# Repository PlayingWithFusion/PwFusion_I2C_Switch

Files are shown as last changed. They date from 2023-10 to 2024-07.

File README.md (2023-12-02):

# PwFusion_I2C_Switch

Are you looking for a way to take your project to the next level? Playing with Fusion's I2C Switch board is the way to go! This device greatly simplifies connectivity to a microcontroller through the QWIIC system. The typical 2 wires required to a toggle switch with a microcontroller can be reduced to one QWIIC cable. You can even chain multiple QWIIC devices together for maximum wiring efficiency! If that isn't enough, Playing with Fusion provides Arduino libraries to make writing code for these boards as easy as possible! Weather you are a beginner looking for a simple introduction to the world of hobbyist electronics or an advanced user looking for a rapid prototyping tool, Playing with Fusion's I2C Switch is right for you!

## I2C Addresses

| ADR | Address |
| --- | --- |
| uncut | 0x13  |
| cut | 0x14  |

Each Playing with Fusion I2C switch board comes with 2 available I2C addresses, which can be easily selected by disconnecting a jumper on the printed circuit board. This allows for 2 toggle switch boards to be used on the same QWIIC chain. If you would like more than 2, see docs/Programming Instructions and flash a modified firmware with additional I2C address options.

## Example Projects
RC Transmitter: https://github.com/PlayingWithFusion/RC_Transmitter

## Related
| Page | Link |
| --- | --- |
| PwFusion_I2C_Toggle_Arduino_Library: | https://github.com/PlayingWithFusion/PwFusion_I2C_Toggle_Arduino_Library |
| PwFusion_Data_Transfer: | https://github.com/PlayingWithFusion/PwFusion_Data_Transfer |
| IFB-40001 PwFusion_I2C_Encoder: | https://github.com/PlayingWithFusion/PwFusion_I2C_Encoder |
| IFB-40002 PwFusion_I2C_Joystick:  |  https://github.com/PlayingWithFusion/PwFusion_I2C_Joystick |
| IFB-40003 PwFusion_I2C_Switch: | https://github.com/PlayingWithFusion/PwFusion_I2C_Switch |
| IFB-40004 PwFusion_I2C_Buttons:  | https://github.com/PlayingWithFusion/PwFusion_I2C_Buttons |

Visit https://www.playingwithfusion.com/ for more information.

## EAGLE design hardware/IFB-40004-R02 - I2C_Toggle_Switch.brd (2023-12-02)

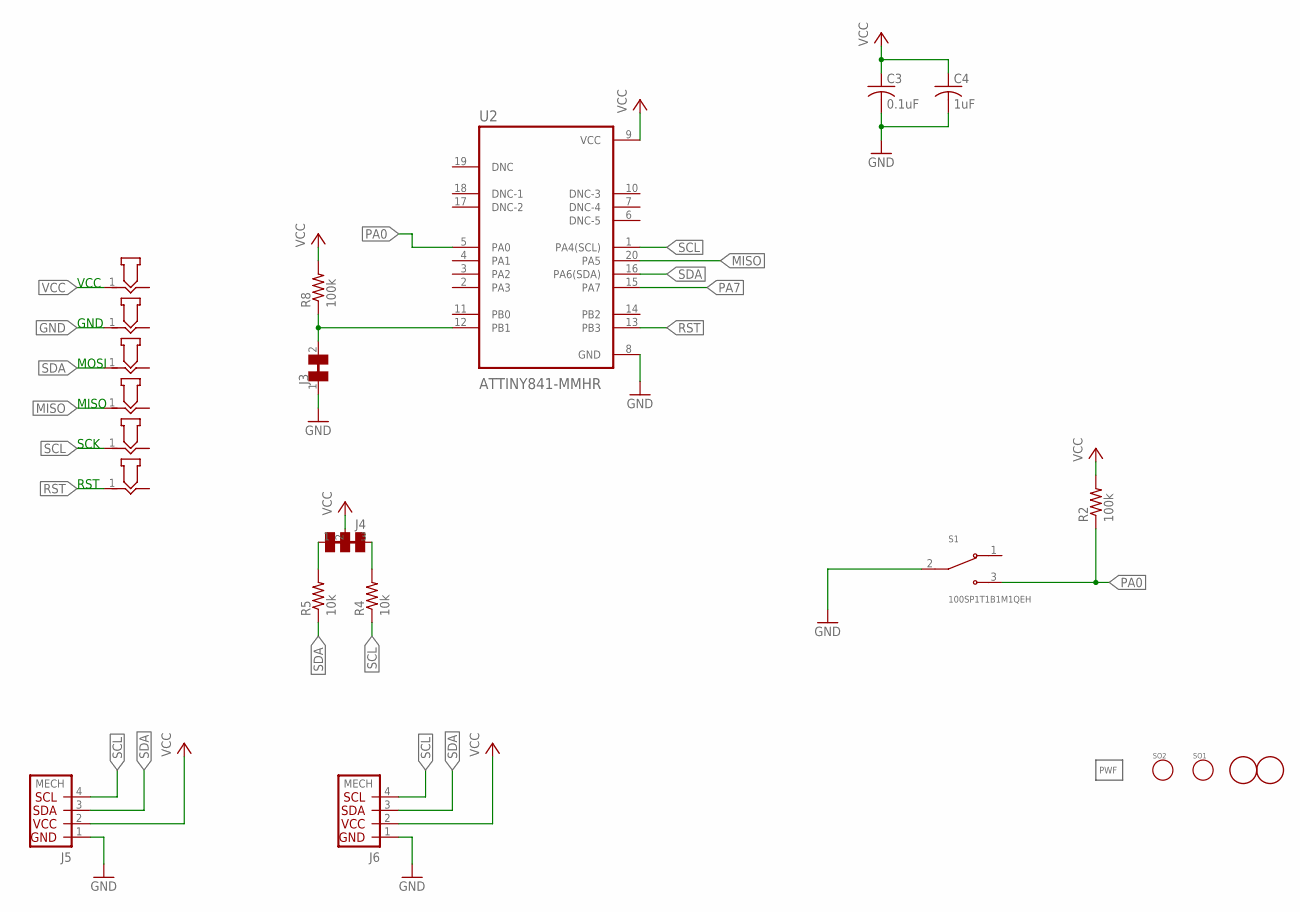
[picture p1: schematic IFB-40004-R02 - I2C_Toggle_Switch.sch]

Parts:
C3: 0.1uF; C0603K
C4: 1uF; C0603K
GND: POGO_PAD; P50_POGO_BOARD_CONTACT_12MIL
J3: CUTTABLE_JUMPER; SMT_CUTTABLE_JUMPER
J4: CUT_JUMPER_2X; SMT_2X_CUTTABLE_JUMPER
J5, J6: QWIICSIDE; SM04B-SRSS-TB
LOGO1: PWF_LOGOPWF-5MM-SS; LOGO_5MM_STEIN
MISO: POGO_PAD; P50_POGO_BOARD_CONTACT_12MIL
MOSI: POGO_PAD; P50_POGO_BOARD_CONTACT_12MIL
R2, R8: 100k; R0603
R4, R5: 10k; R0603
RST: POGO_PAD; P50_POGO_BOARD_CONTACT_12MIL
S1: 100SP1T1B1M1QEH; SW_100SP1T1B1M1QEH
SCK: POGO_PAD; P50_POGO_BOARD_CONTACT_12MIL
SO1, SO2: STAND_OFFNO4_TIGHT; STANDOFF_NO4_TIGHT
U2: ATTINY841-MMHR; QFN45P300X300X85-21N
U$2, U$3: FIDUCIAL; FIDUCIAL_1MM
VCC: POGO_PAD; P50_POGO_BOARD_CONTACT_12MIL

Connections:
GND: C3.2, C4.2, GND.1, J3.1, J5.1, J6.1, S1.2, U2.8 (GND)
MISO: MISO.1, U2.20 (PA5)
unnamed: J3.2, R8.1, U2.12 (PB1)
unnamed: J4.1, R5.2
unnamed: J4.3, R4.2
PA0: R2.1, S1.3, U2.5 (PA0)
PA7: U2.15 (PA7)
RST: RST.1, U2.13 (PB3)
SCL: J5.4, J6.4, R4.1, SCK.1, U2.1 (PA4(SCL))
SDA: J5.3, J6.3, MOSI.1, R5.1, U2.16 (PA6(SDA))
VCC: C3.1, C4.1, J4.2, J5.2, J6.2, R2.2, R8.2, U2.9 (VCC), VCC.1

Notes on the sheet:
VCC
GND
MOSI
MISO
SCK
RST

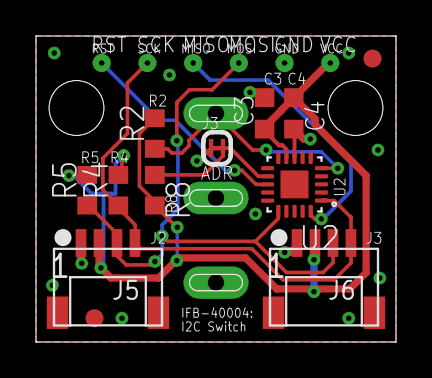
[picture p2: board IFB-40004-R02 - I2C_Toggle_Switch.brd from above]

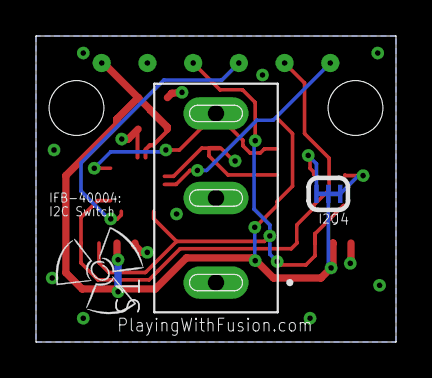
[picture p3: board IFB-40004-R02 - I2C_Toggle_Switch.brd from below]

Board: 2 copper layers, 20.0 x 17.0 mm, 23 parts (3 on the bottom side), 10 nets.

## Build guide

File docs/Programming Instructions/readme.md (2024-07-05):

# Programming Instructions

## Introduction
If you find yourself needing to make changes to the firmware on an interface board, follow these steps to flash your own firmware onto the embedded microcontroller.

All that is required to reporgram a Playing with Fusion I2C board is an AVR programmer. These are available in many forms. This document will cover 2 methods, using a dedicated AVR programmer from Sparkfun and using an Arduino Uno.

## Setup

First, you will need to install the ATtiny Core boards package for the arduino IDE. 

---

**Step 1**

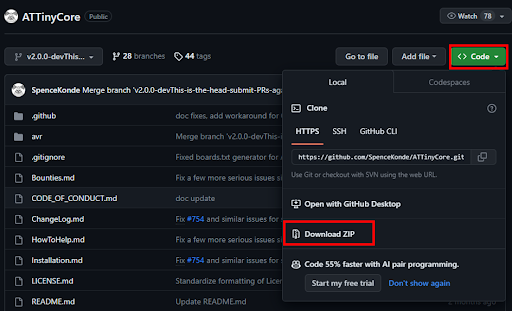
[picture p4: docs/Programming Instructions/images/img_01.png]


Follow the link [here](https://github.com/SpenceKonde/ATTinyCore/tree/v2.0.0-devThis-is-the-head-submit-PRs-against-this) and download the zip file.

---

**Step 2**



Locate the sketchbook directory for your Arduino IDE. You can find this by going to File->Preferences within the Arduino IDE. The sketchbook directory will be listed. Within this directory, locate the hardware folder. If this folder doesn't exist, create it.

---

**Step 3**

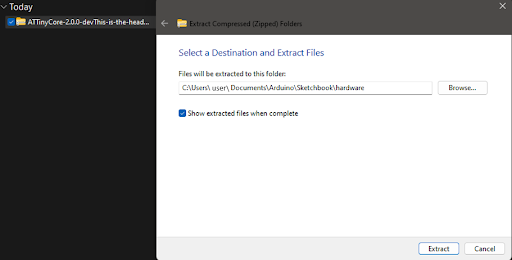
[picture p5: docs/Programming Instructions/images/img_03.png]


Unzip the AtTiny Core folder into the hardware folder in your Arduino Sketchbook folder.

---

**Step 4**

Restart the Arduino IDE.
Within the Arduino IDE, select Tools->Board->ATTinyCore (in sketchbook). This will reveal a list of new ATTiny boards you can now select when programming through the Arduino IDE.

---

**Step 5**

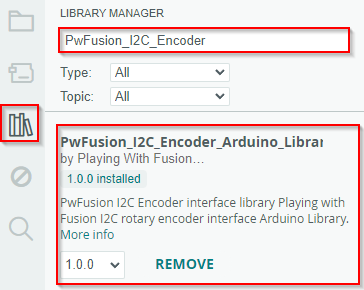
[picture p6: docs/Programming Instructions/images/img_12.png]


Open the library manager on the left side of the Arduino IDE. Install the needed library for the board (i.e. PwFusion_I2C_Encoder_Arduino_Library for the encoder, etc.)
If you are experiencing dependency issues, install the PwFusion_Data_Transfer library.

**Step 6**

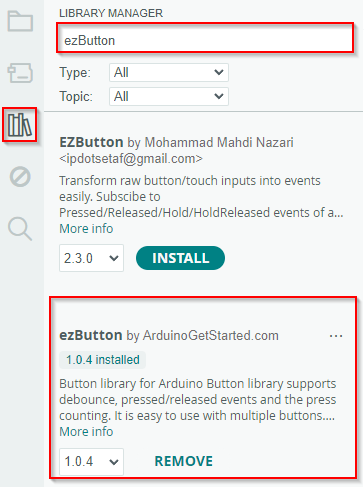
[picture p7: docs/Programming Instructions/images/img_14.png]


Install the ezbutton library as well.

**Step 7**

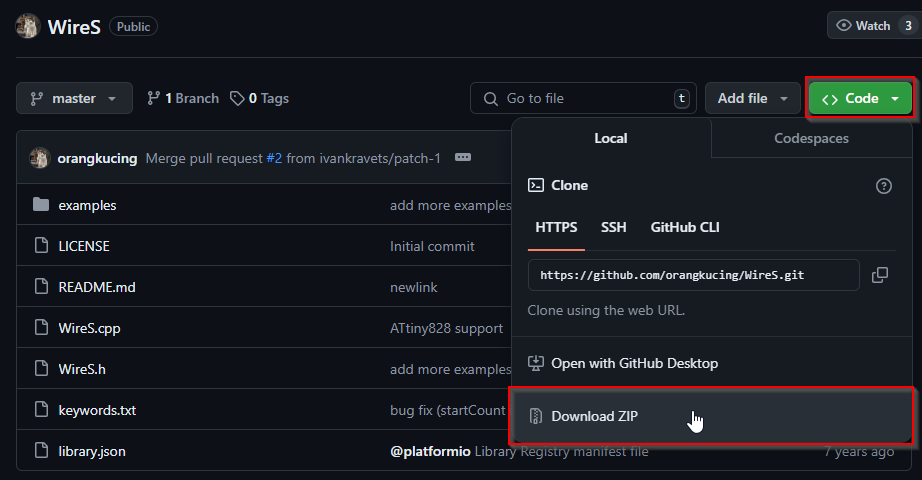
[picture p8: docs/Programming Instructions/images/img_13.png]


ATTiny core boards need a specific I2C library to run. This library can be installed from github [here](https://github.com/orangkucing/WireS). Download this zip file and extract it to your Arduino's sketchbook->libraries folder.

## Sparkfun Tiny Programmer

**Step 1**

Follow Sparkfun's tutorial [here](https://learn.sparkfun.com/tutorials/tiny-avr-programmer-hookup-guide/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) to install the correct drivers. Open the link and scroll down to the "Driver Installation" section.

---

**Step 2**

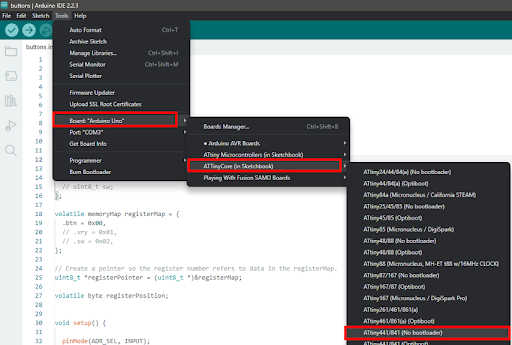
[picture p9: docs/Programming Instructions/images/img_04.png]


Within the Arduino IDE, go to tools->Board->ATTinyCore (in Sketchbook) and select ATtiny441/841 (no bootloader).

---

**Step 3**

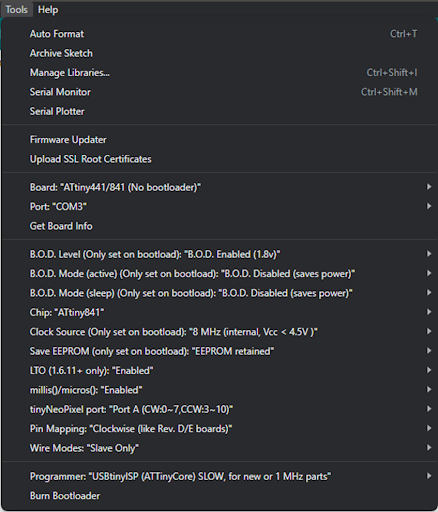
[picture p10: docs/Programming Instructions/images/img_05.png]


Go to tools->Chip and make sure the ATtiny841 is selected.
Go to tools->Programmer and select USBtinyISP (ATTinyCore) SLOW.
Make sure all other settings match as above.

---

**Step 4**

Plug the tiny programmer into a USB port on your device. Connect the pins of the programmer to the respective pads of the I2C interface board you wish to program. This can be done using a pogo pin programming block, or by some standard stacking female pin headders.

Whichever method you choose, it is vital that the pins do not become disconnected during the programming process, otherwise the flash process will fail.

---

**Step 5**

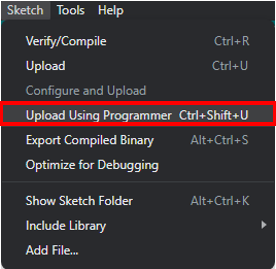
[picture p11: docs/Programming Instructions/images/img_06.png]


In the Arduino IDE, go to sketch->Upload using programmer.
Keep the programmer pins to the pads of the PCB until the flashing process is complete.

---

## Arduino as ISP

**Step 1**

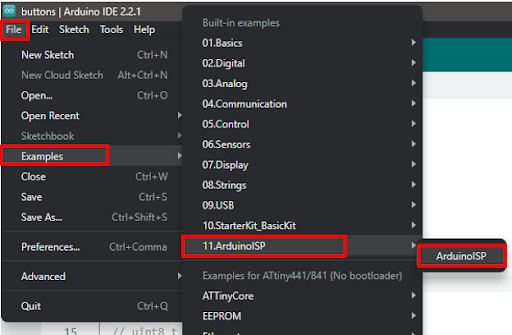
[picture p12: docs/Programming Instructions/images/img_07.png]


In the Arduino IDE, go to file->examples->ArduinoISP and select the example sketch. This code will open up in a new window. Upload this to the Arduino Uno you wish to use as the programmer.

---

**Step 2**

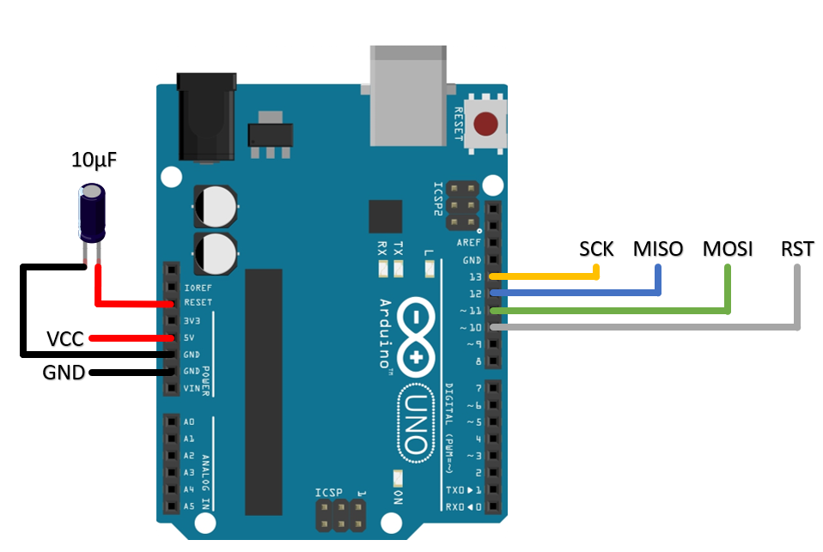
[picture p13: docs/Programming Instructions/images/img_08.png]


Connect the Arduino ISP programmer pins to the pads of the PCB using your prefered method. Connect a 10uF electrolytic capacator between the GND and RST pins of the Arduino Uno. The schematic should look like the diagram above.

---

**Step 3**



Within the Arduino IDE, go to tools->board->ATTinyCore (in sketchbook) and select ATtiny441/841 (no bootloader).

---

**Step 4**



Go to tools and make sure all of the board settings match as above.

---

**Step 5**

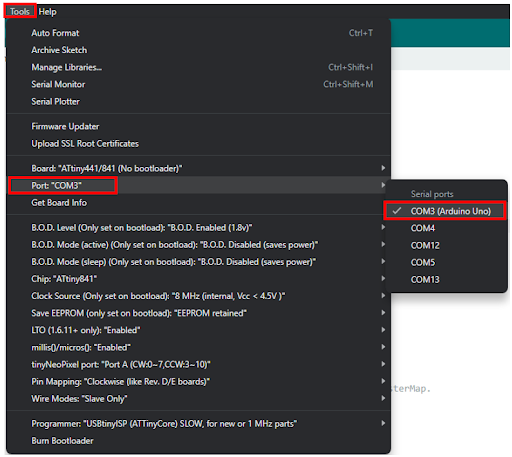
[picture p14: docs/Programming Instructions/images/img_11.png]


Select the part that the Arduino Uno (programmer) is on within the tools menu.

---

**Step 6**



Ensure the arduino is completely connected to the desired PCB's programming pads.
Go to sketch->Upload using programmer

## Additional Links

https://docs.arduino.cc/built-in-examples/arduino-isp/ArduinoISP

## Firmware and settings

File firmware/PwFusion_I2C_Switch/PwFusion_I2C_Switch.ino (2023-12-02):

/***************************************************************************
* File Name: PwFusion_I2C_Switch.ino
* Processor/Platform: ATtiny841-MMHR (tested)
* Development Environment: Arduino 2.1.1
*
* Designed for use with with Playing With Fusion IFB-40004 I2C Switch
* Copyright � 2023 Playing With Fusion, Inc.
* SOFTWARE LICENSE AGREEMENT: This code is released under the MIT License.
*
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
* Playing With Fusion, Inc. invests time and resources developing open-source
* code. Please support Playing With Fusion and continued open-source
* development by buying products from Playing With Fusion!
*
* **************************************************************************
* ADDITIONAL NOTES:
* This file contains functions to flash an AtTiny841-MMHR included in
* the Playing with Fusion i2c toggle switch interface board (IFB-40004).
* Funcionality is as described below:
*   - Read values from the toggle switch componet
*   - Pack values into a register struct
*   - Send values over the i2c bus when requested
***************************************************************************/

#include <WireS.h>
#include <ezButton.h>


uint8_t address0 = 0x13;    // Uncut Address
uint8_t address1 = 0x14;  // Cut Address

// Define pins
#define SW 0
#define ADR_SEL 9

ezButton button(SW);

struct memoryMap {
  uint8_t sw;
};

volatile memoryMap registerMap = {
  .sw = 0x00,
};

// Create a pointer so the register number refers to data in the registerMap.
uint8_t *registerPointer = (uint8_t *)&registerMap;



volatile byte registerPosition;


int btnState;

void setup() {

  pinMode(ADR_SEL, INPUT);

  startI2C();

  button.setDebounceTime(5); // set debounce time to 50 milliseconds

};

void startI2C() {
  if (digitalRead(ADR_SEL) == LOW) {
    Wire.begin(address0);
  } else {
    Wire.begin(address1);
  }

  Wire.onReceive(receiveEvent);
  Wire.onRequest(requestEvent);
}


void loop() {

  // Collect data from the joystick button
  button.loop(); // MUST call the loop() function first
  if(button.isPressed())
    btnState = 1;

  if(button.isReleased())
    btnState = 0;
  
  // Store the mapped values from the switch in the registerMap struct
  registerMap.sw = btnState;
}
 
// Gets called when the ATtiny receives an i2c request
void requestEvent() {
  Wire.write(*(registerPointer + registerPosition));
}

// Gets called when the ATtiny revieves an i2c transmission
void receiveEvent(byte howMany) {
  if (howMany < 1) return;

  // Set the register offset position to what the master requests.
  registerPosition = Wire.read();
  howMany--;
  if (!howMany) return;
}

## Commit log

2023-10-08 hardware and links
    [IFB-40004-R01 - I2C_Toggle_Switch.brd, IFB-40004-R01 - I2C_Toggle_Switch.sch]
2023-12-02 updated hardware files
    [IFB-40004-R02 - I2C_Toggle_Switch.brd, IFB-40004-R02 - I2C_Toggle_Switch.sch]

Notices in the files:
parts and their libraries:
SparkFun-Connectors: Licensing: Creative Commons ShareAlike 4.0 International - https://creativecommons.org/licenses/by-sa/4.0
